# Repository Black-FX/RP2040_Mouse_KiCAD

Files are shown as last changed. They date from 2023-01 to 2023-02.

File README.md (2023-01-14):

# RP2040_Mouse_KiCAD
This is the hardware side of an RP2040 USB to Quadrature mouse adaptor used with retro computers, the software is available at https://github.com/Black-FX/RP2040_Mouse

A PDF of the scematic is available in [Here](PDF/scematic.pdf)

Glamour shots

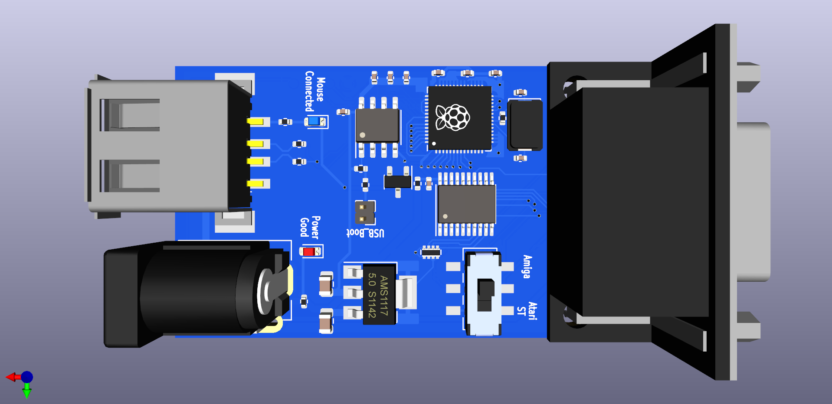
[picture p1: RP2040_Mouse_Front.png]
Front


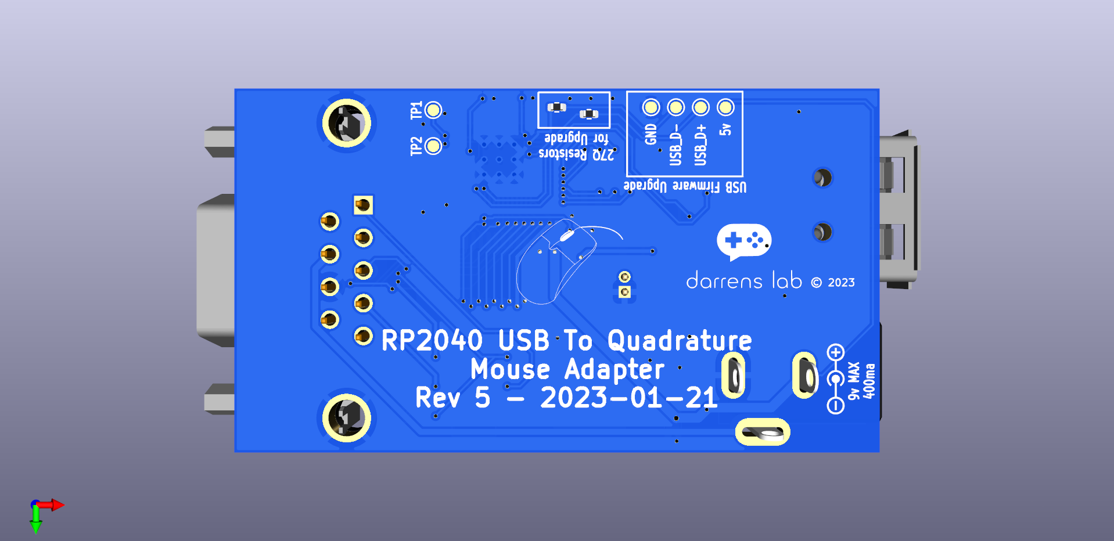
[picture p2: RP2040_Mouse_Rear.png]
Rear


# Ordering

You can order the boards here:

[PCBWay](https://www.pcbway.com/project/shareproject/RP2040_USB_Mouse_to_Quadrature_15de42f1.html)

I sell pre-assembled and programmed ones here:

[Tindie](https://www.tindie.com/products/darrens_lab/rp2040-usb-to-quadrature-mouse-adaptor/)

[EBay](https://www.ebay.com/usr/darrens_lab_nz?_trksid=p2047675.m145687.l151929)

[Trademe NZ & Aus](https://www.trademe.co.nz/a/search?member_listing=7404797&bof=McH9Ulww)

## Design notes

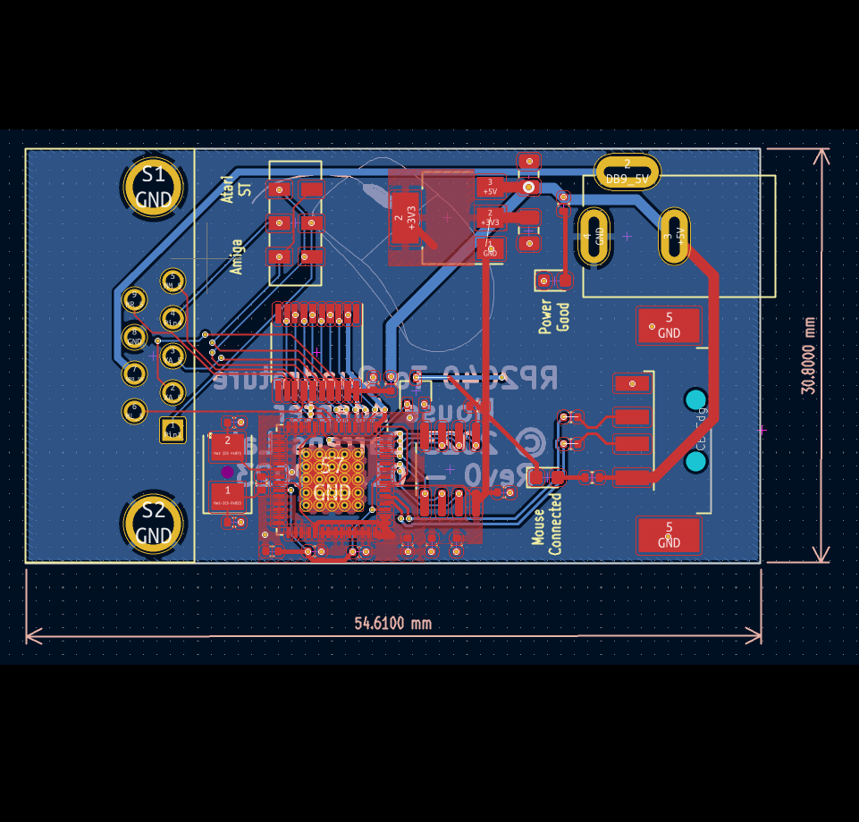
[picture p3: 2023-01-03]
PCB_Layout.png

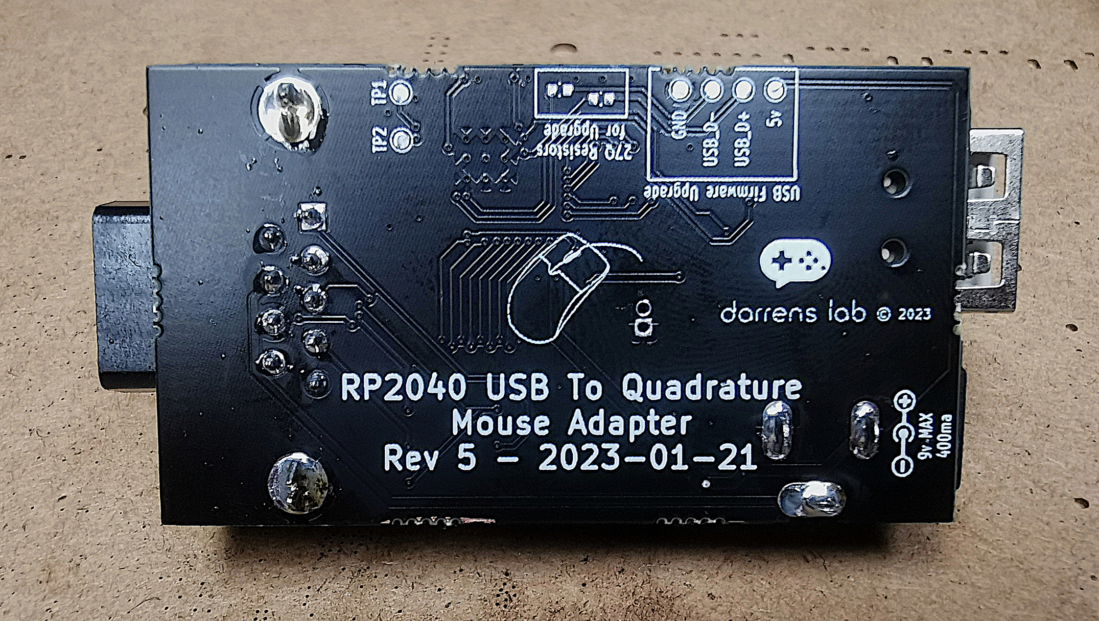
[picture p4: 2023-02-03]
images/IMG_20230203_174929_edit_710155273955179.jpg

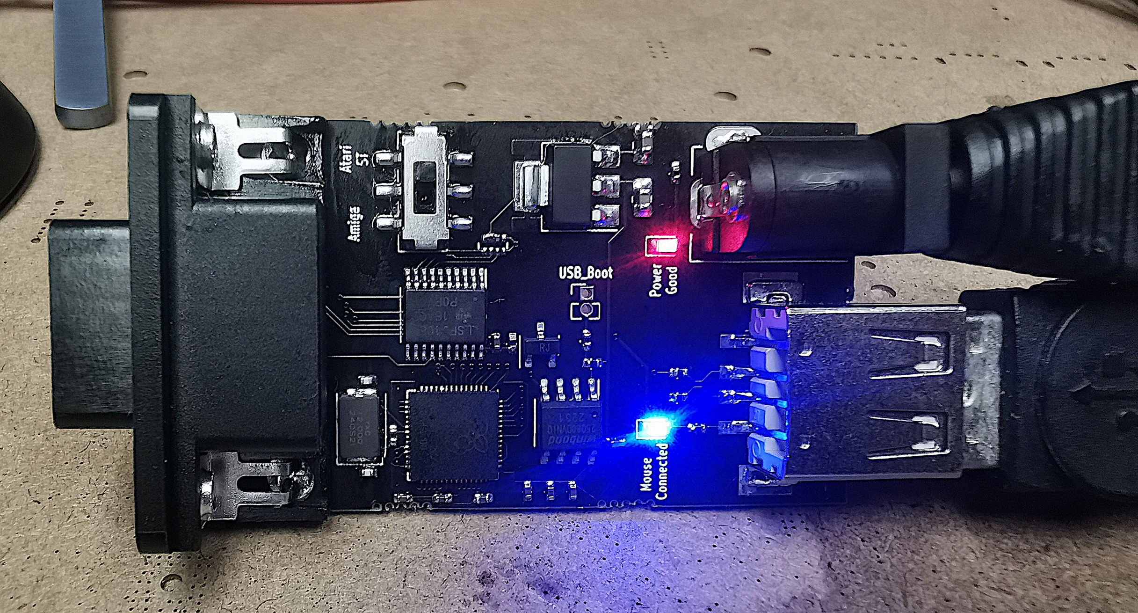
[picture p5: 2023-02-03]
images/IMG_20230203_174809_edit_710135319617161.jpg

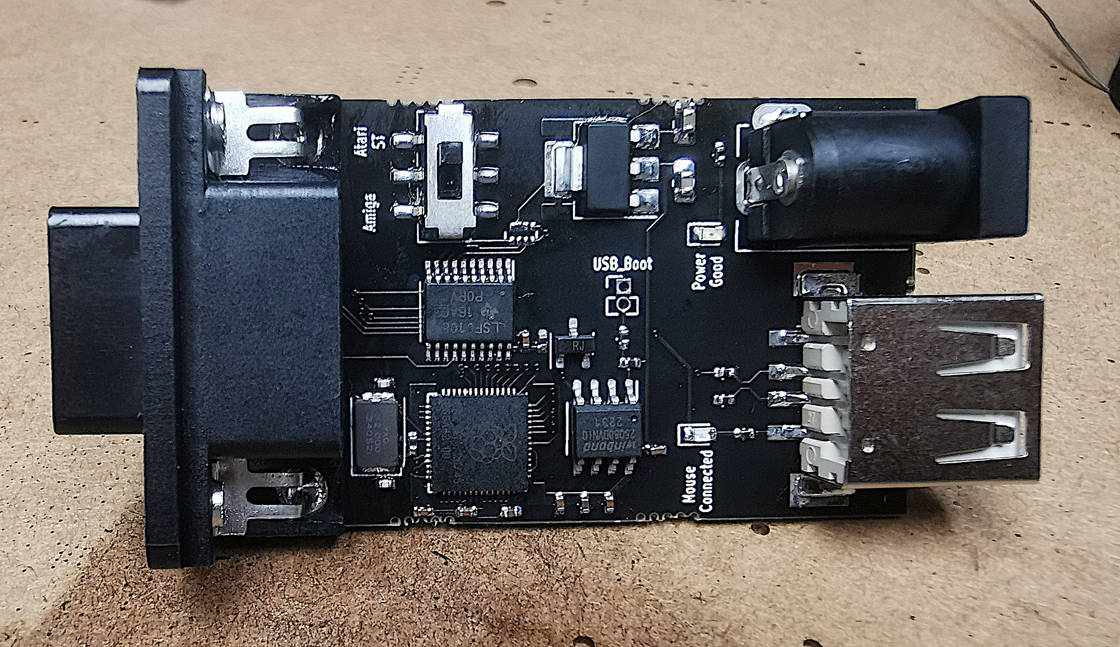
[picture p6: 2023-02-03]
images/IMG_20230203_174900_edit_710110974966644.jpg

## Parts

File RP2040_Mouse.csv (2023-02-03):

Source: | /home/darren/creations/eda/RP2040_Mouse_KiCAD/RP2040_Mouse.kicad_sch
Date: | Mon 30 Jan 2023 19:51:02
Tool: | Eeschema 7.0.0-rc2-unknown-5beb79bbdc~164~ubuntu22.04.1
Generator: | /usr/share/kicad/plugins/bom_csv_grouped_by_value.py
Component Count: | 42
Individual Components:
Item | Qty | Reference(s) | Value | LibPart | Footprint | Datasheet | AVAILABILITY | DESCRIPTION | MF | MP | PACKAGE | PRICE | Part
 |  | C1 | 10u | Device:C_Polarized | Capacitor_SMD:C_0805_2012Metric | ~ |  |  |  |  |  |  | TCJN106M006R0500E
 |  | C2 | 10u | Device:C_Polarized | Capacitor_SMD:C_0805_2012Metric | ~ |  |  |  |  |  |  | TCJN106M006R0500E
 |  | C3 | 100n | Device:C | Capacitor_SMD:C_0402_1005Metric | ~
 |  | C4 | 100n | Device:C | Capacitor_SMD:C_0402_1005Metric | ~
 |  | C5 | 30p | Device:C | Capacitor_SMD:C_0402_1005Metric | ~
 |  | C6 | 30p | Device:C | Capacitor_SMD:C_0402_1005Metric | ~
 |  | C7 | 100n | Device:C | Capacitor_SMD:C_0402_1005Metric | ~
 |  | C8 | 100n | Device:C | Capacitor_SMD:C_0402_1005Metric | ~
 |  | C9 | 1u | Device:C | Capacitor_SMD:C_0402_1005Metric | ~
 |  | C10 | 100n | Device:C | Capacitor_SMD:C_0402_1005Metric | ~
 |  | C11 | 1u | Device:C | Capacitor_SMD:C_0402_1005Metric | ~ |  |  |  |  |  |  | CM05X7S105M04AH-HE
 |  | C12 | 100n | Device:C | Capacitor_SMD:C_0402_1005Metric | ~
 |  | D1 | LED | Device:LED | LED_SMD:LED_0603_1608Metric | ~
 |  | D2 | LED | Device:LED | LED_SMD:LED_0603_1608Metric | ~
 |  | J1 | DB9_Male | Connector:DB9_Male | My Library:ASSMANN_A-DF_09_A_KG-T2S | ~
 |  | J2 | Barrel_Jack_Switch | LSF0108:DC-005 | Library:NINIGI_DC-005 |  | Unavailable | Conn Dc Power Jack 2.1mm | Best Inc. | DC-005 | None | None
 |  | J3 | USB_A | Connector:USB_A | Library:USB_A_China | ~
 |  | JP1 | USB_Boot | Jumper:Jumper_2_Open | Connector_PinHeader_1.27mm:PinHeader_1x02_P1.27mm_Vertical | ~
 |  | Q1 | Q_NPN_BEC | Device:Q_NPN_BEC | Package_TO_SOT_SMD:SOT-23-3 | ~
 |  | R1 | 10K | Device:R_Small_US | Resistor_SMD:R_0402_1005Metric | ~
 |  | R2 | 180K | Device:R_Small_US | Resistor_SMD:R_0402_1005Metric | ~
 |  | R3 | 1K5 | Device:R_Small_US | Resistor_SMD:R_0402_1005Metric | ~
 |  | R4 | 22R | Device:R_Small_US | Resistor_SMD:R_0402_1005Metric | ~
 |  | R5 | 22R | Device:R_Small_US | Resistor_SMD:R_0402_1005Metric | ~
 |  | R6 | 1K5 | Device:R_Small_US | Resistor_SMD:R_0402_1005Metric | ~
 |  | R7 | 1K5 | Device:R_Small_US | Resistor_SMD:R_0402_1005Metric | ~
 |  | R8 | 1K5 | Device:R_Small_US | Resistor_SMD:R_0402_1005Metric | ~
 |  | R9 | 22R | Device:R_Small_US | Resistor_SMD:R_0402_1005Metric | ~
 |  | R10 | 22R | Device:R_Small_US | Resistor_SMD:R_0402_1005Metric | ~
 |  | RN1 | R_Pack04 | Device:R_Pack04 | Resistor_SMD:R_Array_Concave_4x0402 | ~
 |  | SW1 | SW_DPDT_x2 | Switch:SW_DPDT_x2 | Button_Switch_SMD:SW_DPDT_CK_JS202011JCQN | ~
 |  | TP1 | SWD | Connector:TestPoint | TestPoint:TestPoint_Pad_D1.0mm | ~
 |  | TP2 | SWCLK | Connector:TestPoint | TestPoint:TestPoint_Pad_D1.0mm | ~
 |  | TP3 | USB_D+ | Connector:TestPoint | TestPoint:TestPoint_Pad_D1.0mm | ~
 |  | TP4 | USB_D- | Connector:TestPoint | TestPoint:TestPoint_Pad_D1.0mm | ~
 |  | TP5 | 5v | Connector:TestPoint | TestPoint:TestPoint_Pad_D1.0mm | ~
 |  | TP6 | GND | Connector:TestPoint | TestPoint:TestPoint_Pad_D1.0mm | ~
 |  | U1 | LSF0108PWR | LSF0108:LSF0108PWR | Package_SO:TSSOP-20_4.4x6.5mm_P0.65mm
 |  | U2 | RP2040 | RP2040:RP2040 | Library:RP2040-QFN-56
 |  | U3 | AT25SF081B-SSHD-T | Memory_Flash:W25Q32JVZP | Package_SO:SOIC-8-1EP_3.9x4.9mm_P1.27mm_EP2.29x3mm | http://www.winbond.com/resource-files/w25q32jv%20revg%2003272018%20plus.pdf
 |  | U4 | AMS1117-3.3 | Regulator_Linear:AMS1117-3.3 | Package_TO_SOT_SMD:SOT-223-3_TabPin2 | http://www.advanced-monolithic.com/pdf/ds1117.pdf
 |  | Y1 | 12MHZ | Device:Crystal | Crystal:Crystal_SMD_5032-2Pin_5.0x3.2mm | ~
Collated Components:
Item | Qty | Reference(s) | Value | LibPart | Footprint | Datasheet | AVAILABILITY | DESCRIPTION | MF | MP | PACKAGE | PRICE | Part
1 | 2 | C1, C2 | 10u | Device:C_Polarized | Capacitor_SMD:C_0805_2012Metric | ~ |  |  |  |  |  |  | TCJN106M006R0500E
2 | 6 | C3, C4, C7, C8, C10, C12 | 100n | Device:C | Capacitor_SMD:C_0402_1005Metric | ~
3 | 2 | C5, C6 | 30p | Device:C | Capacitor_SMD:C_0402_1005Metric | ~
4 | 2 | C9, C11 | 1u | Device:C | Capacitor_SMD:C_0402_1005Metric | ~ |  |  |  |  |  |  | CM05X7S105M04AH-HE
5 | 2 | D1, D2 | LED | Device:LED | LED_SMD:LED_0603_1608Metric | ~
6 | 1 | J1 | DB9_Male | Connector:DB9_Male | My Library:ASSMANN_A-DF_09_A_KG-T2S | ~
7 | 1 | J2 | Barrel_Jack_Switch | LSF0108:DC-005 | Library:NINIGI_DC-005 |  | Unavailable | Conn Dc Power Jack 2.1mm | Best Inc. | DC-005 | None | None
8 | 1 | J3 | USB_A | Connector:USB_A | Library:USB_A_China | ~
9 | 1 | JP1 | USB_Boot | Jumper:Jumper_2_Open | Connector_PinHeader_1.27mm:PinHeader_1x02_P1.27mm_Vertical | ~
10 | 1 | Q1 | Q_NPN_BEC | Device:Q_NPN_BEC | Package_TO_SOT_SMD:SOT-23-3 | ~
11 | 1 | R1 | 10K | Device:R_Small_US | Resistor_SMD:R_0402_1005Metric | ~
12 | 1 | R2 | 180K | Device:R_Small_US | Resistor_SMD:R_0402_1005Metric | ~
13 | 4 | R3, R6, R7, R8 | 1K5 | Device:R_Small_US | Resistor_SMD:R_0402_1005Metric | ~
14 | 4 | R4, R5, R9, R10 | 22R | Device:R_Small_US | Resistor_SMD:R_0402_1005Metric | ~
15 | 1 | RN1 | R_Pack04 | Device:R_Pack04 | Resistor_SMD:R_Array_Concave_4x0402 | ~
16 | 1 | SW1 | SW_DPDT_x2 | Switch:SW_DPDT_x2 | Button_Switch_SMD:SW_DPDT_CK_JS202011JCQN | ~
17 | 1 | TP1 | SWD | Connector:TestPoint | TestPoint:TestPoint_Pad_D1.0mm | ~
18 | 1 | TP2 | SWCLK | Connector:TestPoint | TestPoint:TestPoint_Pad_D1.0mm | ~
19 | 1 | TP3 | USB_D+ | Connector:TestPoint | TestPoint:TestPoint_Pad_D1.0mm | ~
20 | 1 | TP4 | USB_D- | Connector:TestPoint | TestPoint:TestPoint_Pad_D1.0mm | ~
21 | 1 | TP5 | 5v | Connector:TestPoint | TestPoint:TestPoint_Pad_D1.0mm | ~
22 | 1 | TP6 | GND | Connector:TestPoint | TestPoint:TestPoint_Pad_D1.0mm | ~
23 | 1 | U1 | LSF0108PWR | LSF0108:LSF0108PWR | Package_SO:TSSOP-20_4.4x6.5mm_P0.65mm
24 | 1 | U2 | RP2040 | RP2040:RP2040 | Library:RP2040-QFN-56
25 | 1 | U3 | AT25SF081B-SSHD-T | Memory_Flash:W25Q32JVZP | Package_SO:SOIC-8-1EP_3.9x4.9mm_P1.27mm_EP2.29x3mm | http://www.winbond.com/resource-files/w25q32jv%20revg%2003272018%20plus.pdf
26 | 1 | U4 | AMS1117-3.3 | Regulator_Linear:AMS1117-3.3 | Package_TO_SOT_SMD:SOT-223-3_TabPin2 | http://www.advanced-monolithic.com/pdf/ds1117.pdf
27 | 1 | Y1 | 12MHZ | Device:Crystal | Crystal:Crystal_SMD_5032-2Pin_5.0x3.2mm | ~

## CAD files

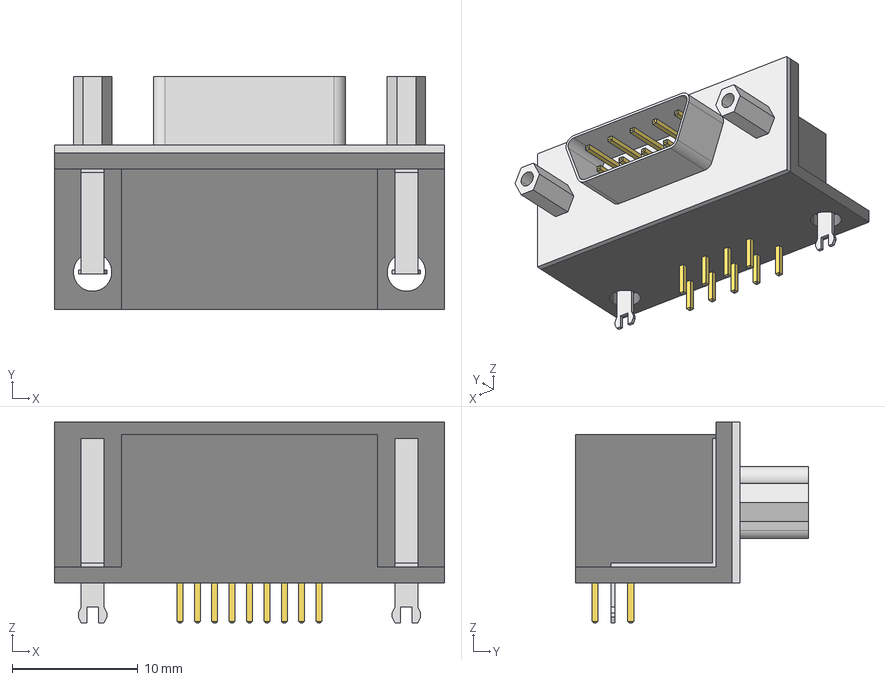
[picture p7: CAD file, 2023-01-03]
3d_models/CONN_A-DF09AKG-T2S_ASM.step
31.1 x 18.6 x 16.0 mm

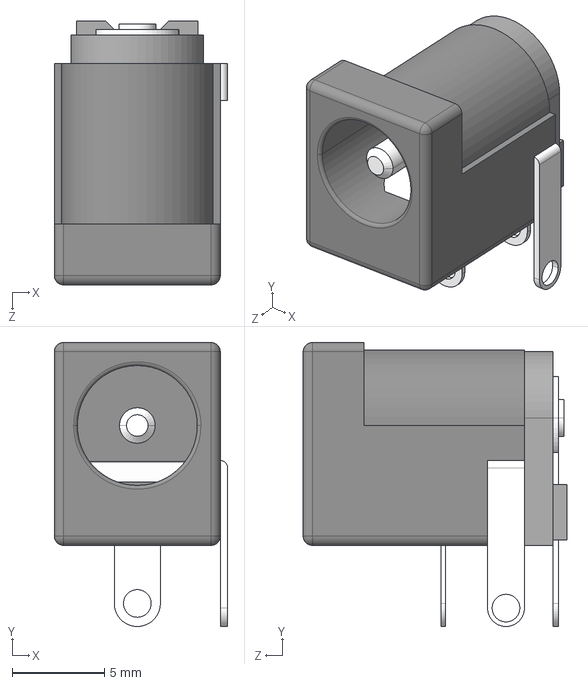
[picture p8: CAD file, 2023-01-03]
3d_models/DC-005.STEP
9.40 x 15.4 x 14.3 mm

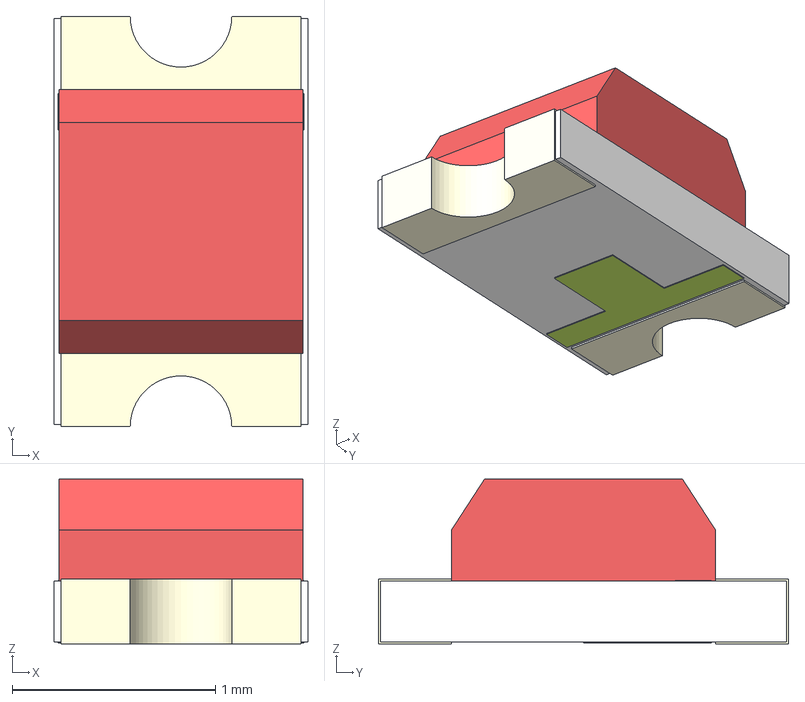
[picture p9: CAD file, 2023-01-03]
3d_models/LED-0805-Red.step
1.25 x 2.02 x 0.81 mm
Pads
Glass
Marks
Chip

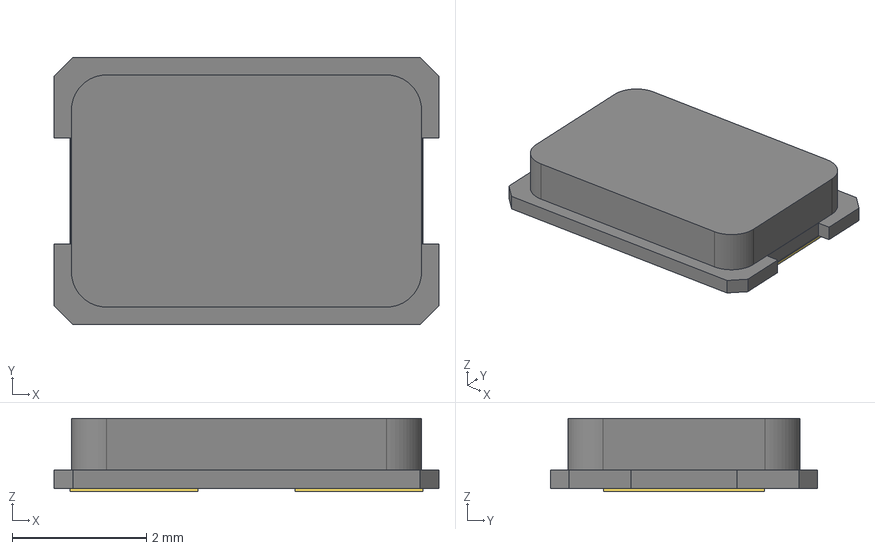
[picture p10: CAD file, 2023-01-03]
3d_models/xtal2_CX5032GB_AVX.step
5.73 x 3.98 x 1.09 mm

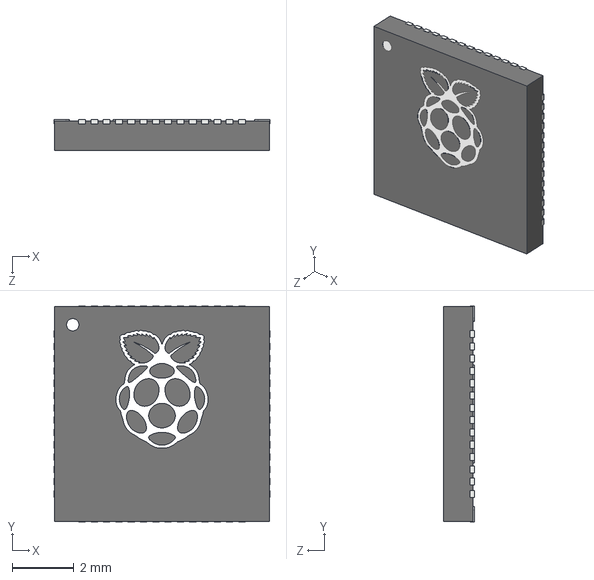
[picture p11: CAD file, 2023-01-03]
3d_models/RP2040_QFN_PACKAGE.STEP
7.02 x 7.02 x 1.00 mm

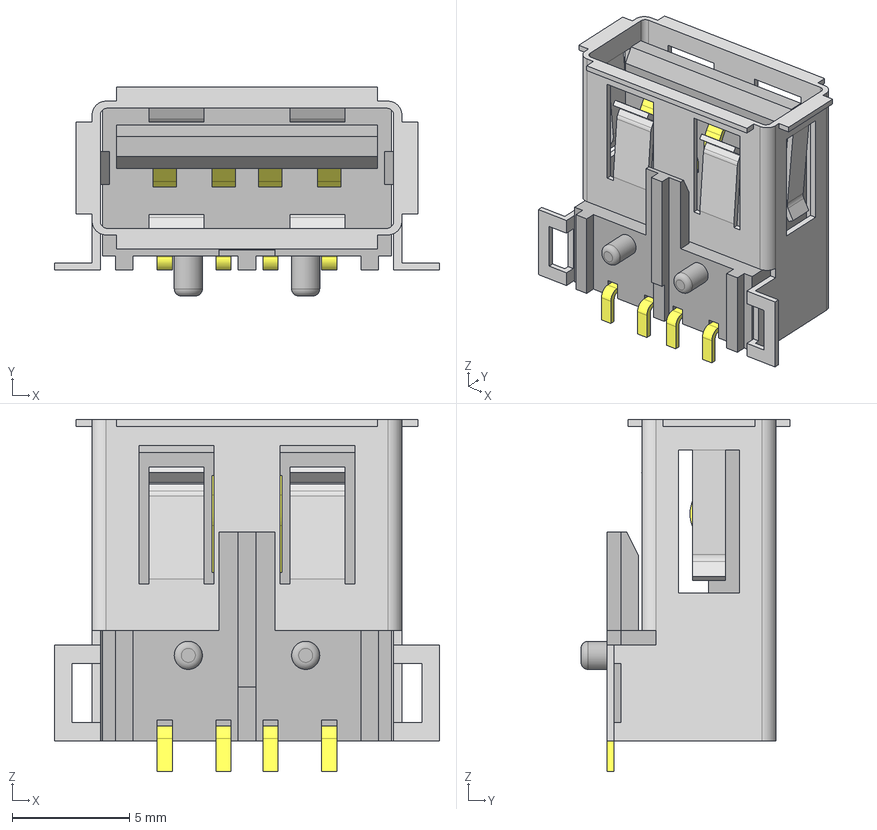
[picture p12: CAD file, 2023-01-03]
3d_models/USB-A-S-F-B-SM2-TR.stp
16.4 x 8.90 x 15.0 mm
USB-A-S-SM2_P
USB-A-S-B-SM2_B
USB-A-S-SM2_S

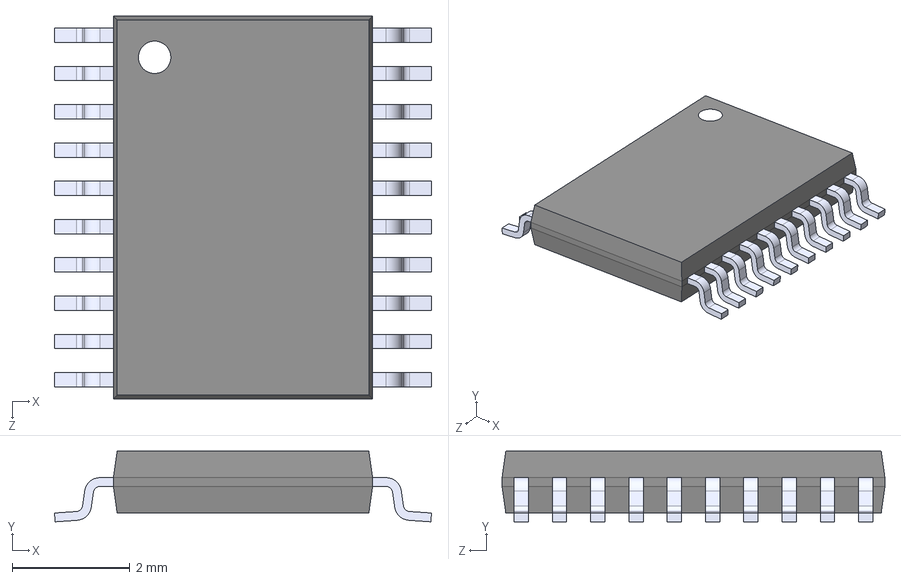
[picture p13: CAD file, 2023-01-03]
3d_models/LSF0108PWR.step
6.40 x 1.20 x 6.50 mm

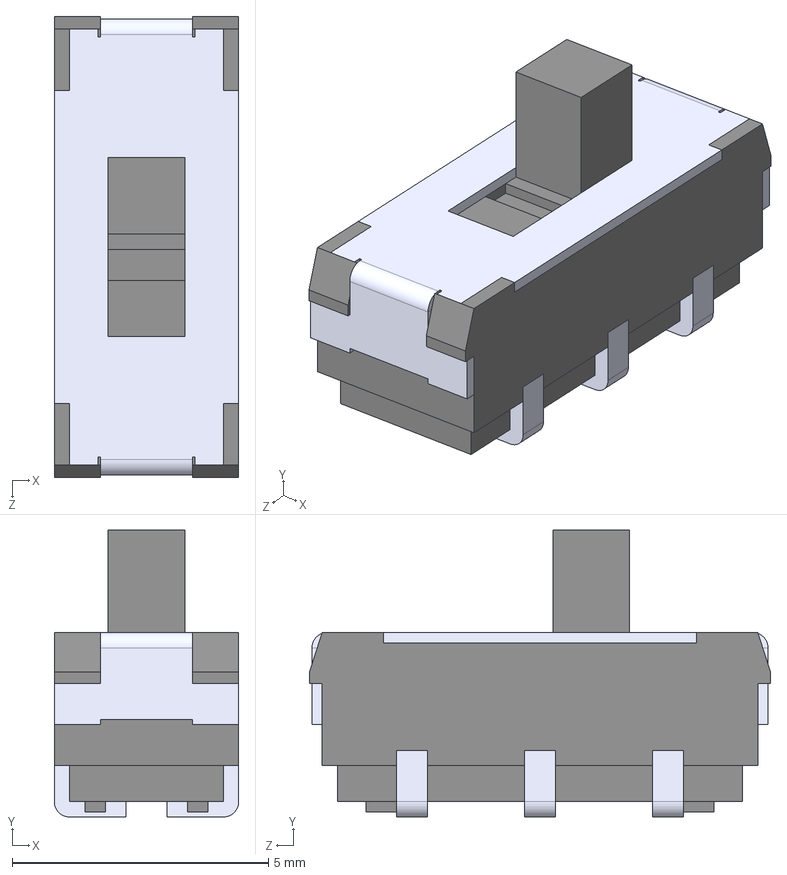
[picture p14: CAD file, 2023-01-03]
3d_models/JS202011JCQN--3DModel-STEP-1.STEP
3.60 x 5.60 x 9.00 mm

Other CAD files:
3d_models/LED-0805-Blue.step

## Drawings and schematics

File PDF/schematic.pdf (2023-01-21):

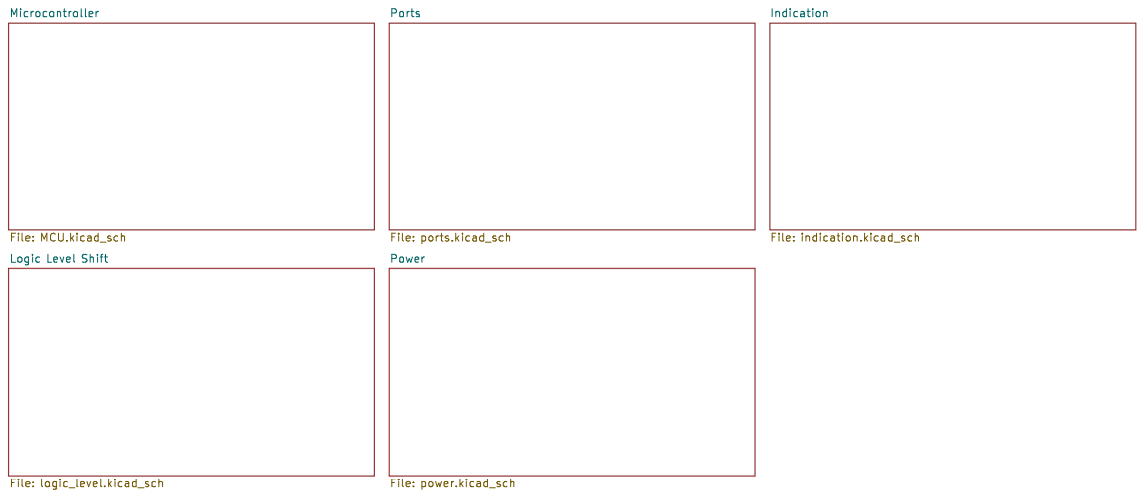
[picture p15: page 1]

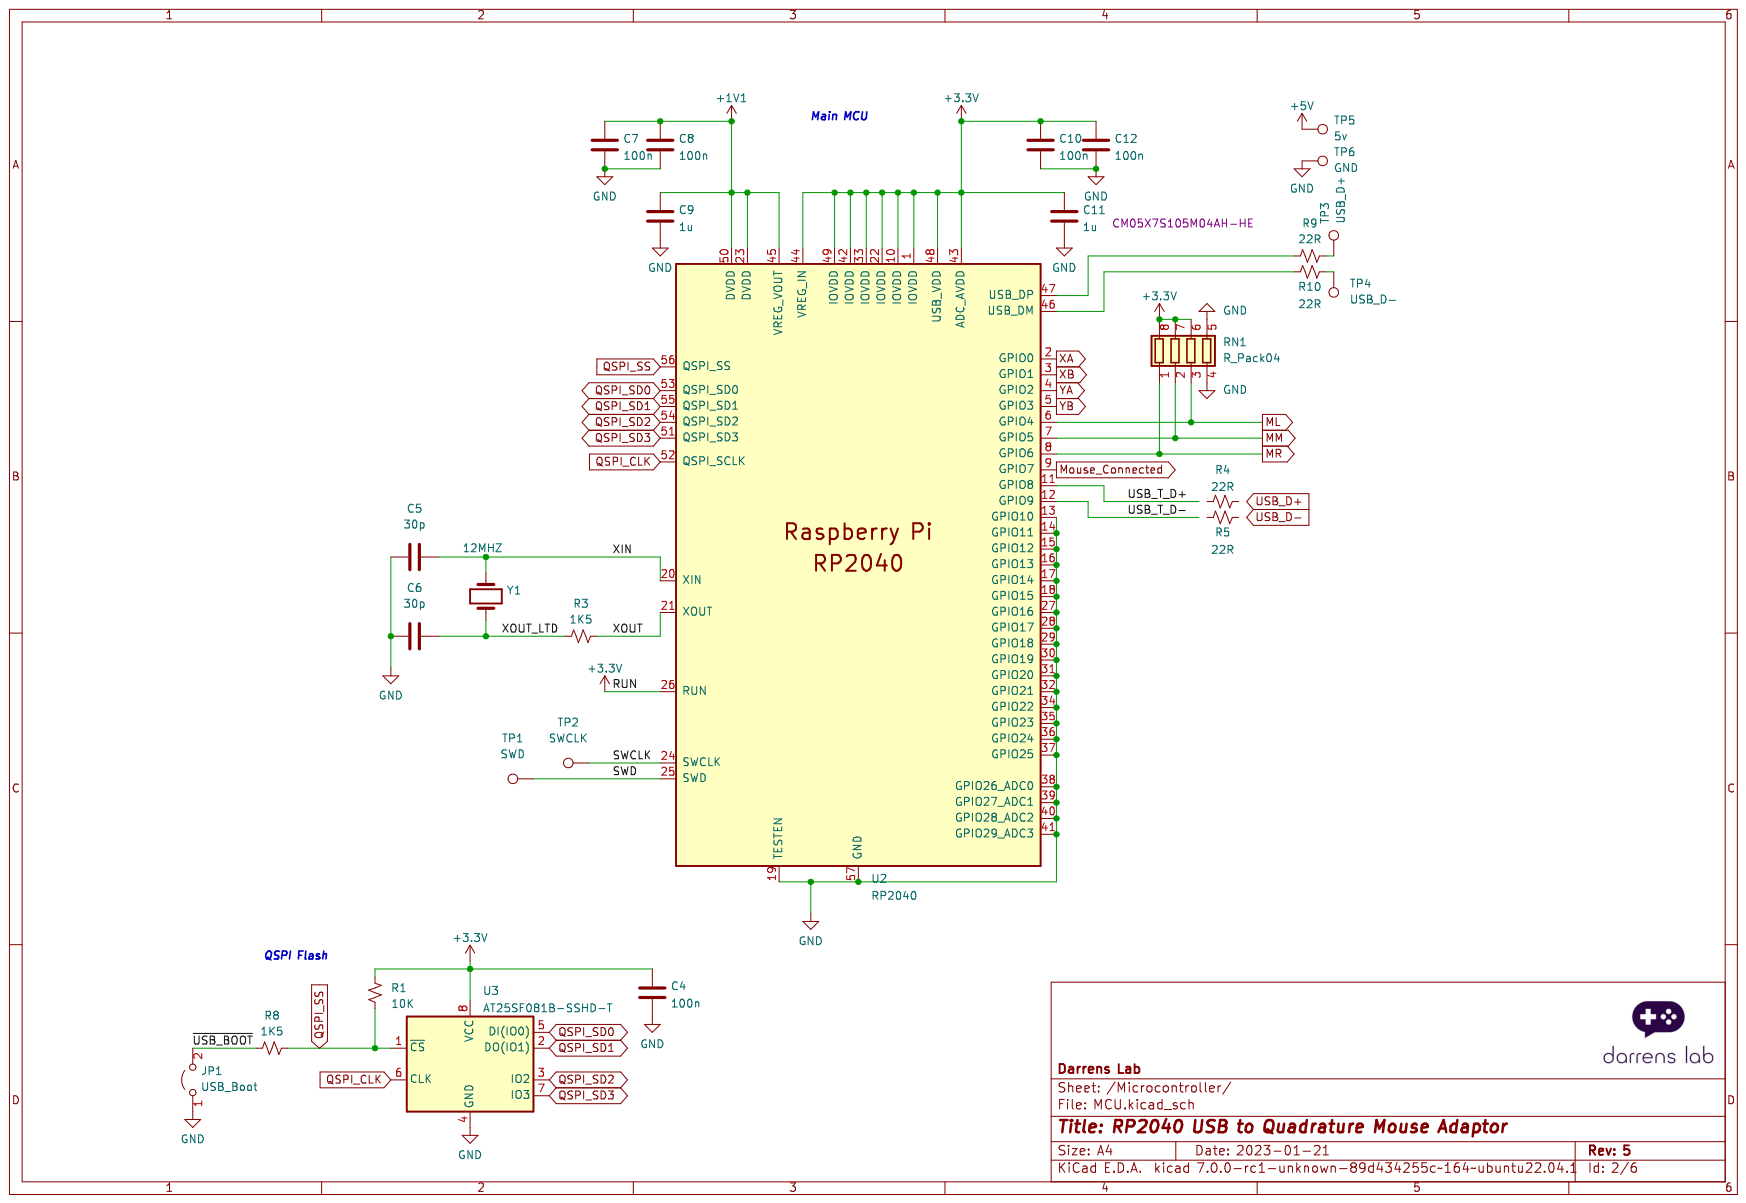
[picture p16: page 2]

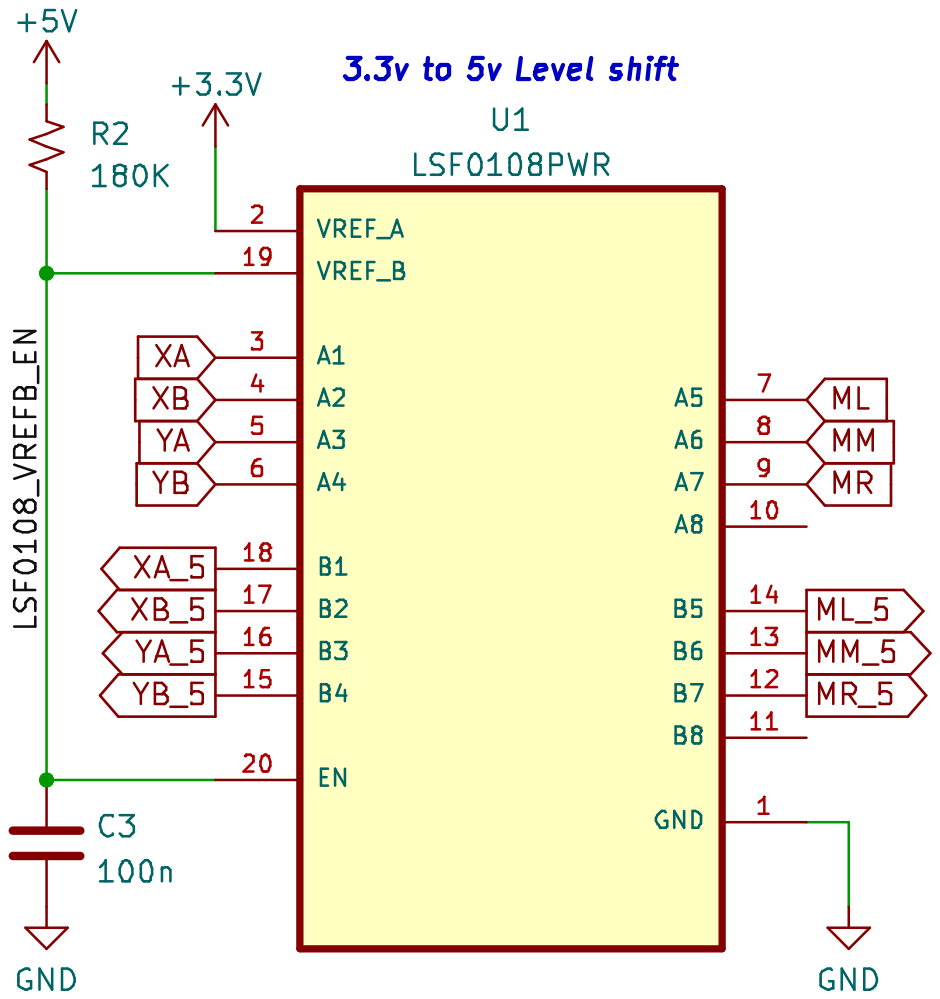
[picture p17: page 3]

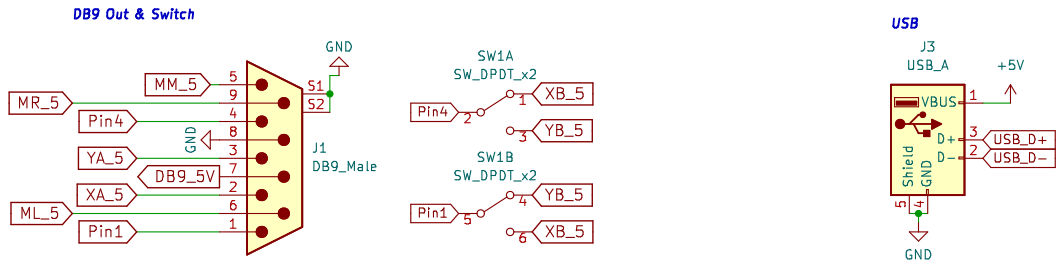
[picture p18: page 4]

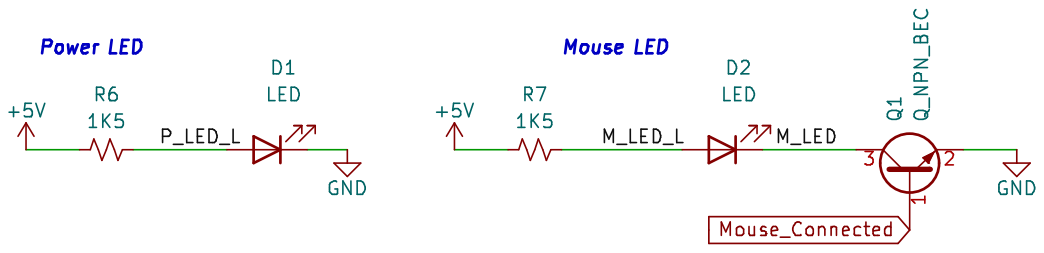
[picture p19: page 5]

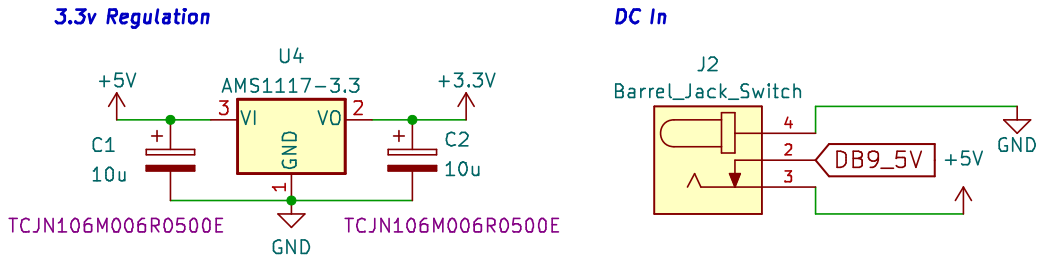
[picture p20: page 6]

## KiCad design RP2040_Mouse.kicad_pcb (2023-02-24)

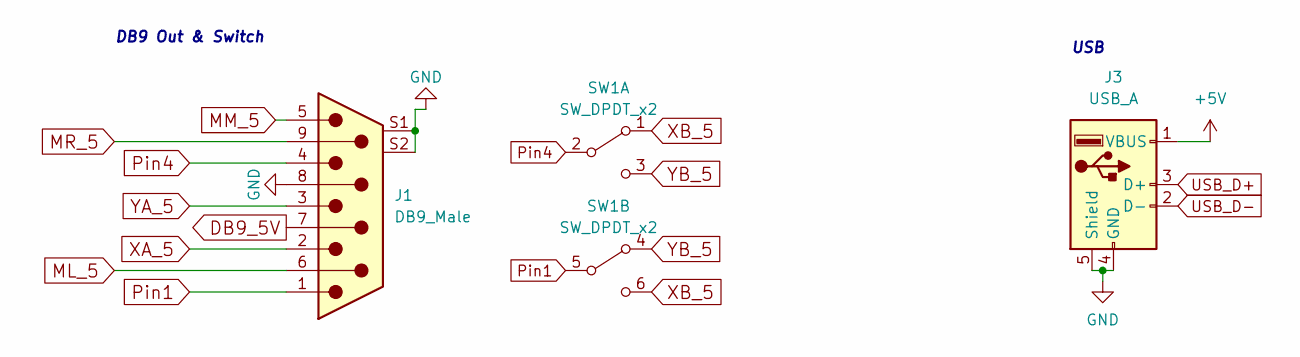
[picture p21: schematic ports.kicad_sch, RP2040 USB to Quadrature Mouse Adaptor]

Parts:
J1: DB9_Male; ASSMANN_A-DF_09_A_KG-T2S
J3: USB_A; USB_A_China
SW1: SW_DPDT_x2; SW_DPDT_CK_JS202011JCQN

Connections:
+5V: J3.1 (VBUS); also elsewhere on the board
DB9_5V: J1.7; also elsewhere on the board
GND: J1.8, J1.S1, J1.S2, J3.4 (GND), J3.5 (Shield); also elsewhere on the board
ML_5: J1.6; also elsewhere on the board
MM_5: J1.5; also elsewhere on the board
MR_5: J1.9; also elsewhere on the board
Pin1: J1.1, SW1.5 (B)
Pin4: J1.4, SW1.2 (B)
USB_D+: J3.3 (D+); also elsewhere on the board
USB_D-: J3.2 (D-); also elsewhere on the board
XA_5: J1.2; also elsewhere on the board
XB_5: SW1.1 (A), SW1.6 (C); also elsewhere on the board
YA_5: J1.3; also elsewhere on the board
YB_5: SW1.3 (C), SW1.4 (A); also elsewhere on the board

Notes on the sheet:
USB
DB9 Out & Switch

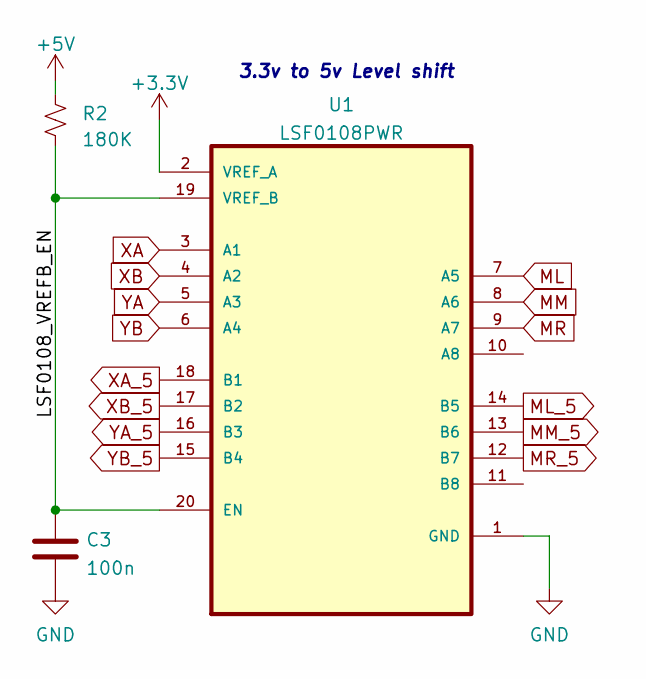
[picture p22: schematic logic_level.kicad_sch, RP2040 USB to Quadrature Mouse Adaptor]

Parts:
C3: 100n; C_0402_1005Metric
R2: 180K; R_0402_1005Metric
U1: LSF0108PWR; TSSOP-20_4.4x6.5mm_P0.65mm

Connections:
+3V3: U1.2 (VREF_A); also elsewhere on the board
+5V: R2.1; also elsewhere on the board
/Logic Level Shift/LSF0108_VREFB_EN: C3.1, R2.2, U1.19 (VREF_B), U1.20 (EN)
GND: C3.2, U1.1 (GND); also elsewhere on the board
ML: U1.7 (A5); also elsewhere on the board
ML_5: U1.14 (B5); also elsewhere on the board
MM: U1.8 (A6); also elsewhere on the board
MM_5: U1.13 (B6); also elsewhere on the board
MR: U1.9 (A7); also elsewhere on the board
MR_5: U1.12 (B7); also elsewhere on the board
XA: U1.3 (A1); also elsewhere on the board
XA_5: U1.18 (B1); also elsewhere on the board
XB: U1.4 (A2); also elsewhere on the board
XB_5: U1.17 (B2); also elsewhere on the board
YA: U1.5 (A3); also elsewhere on the board
YA_5: U1.16 (B3); also elsewhere on the board
YB: U1.6 (A4); also elsewhere on the board
YB_5: U1.15 (B4); also elsewhere on the board

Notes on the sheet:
3.3v to 5v Level shift

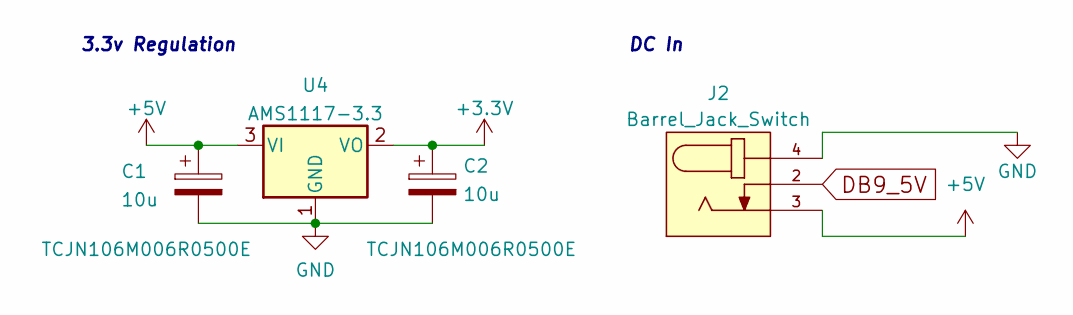
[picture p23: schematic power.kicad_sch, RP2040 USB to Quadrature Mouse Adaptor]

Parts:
C1, C2: 10u; C_0805_2012Metric; Part TCJN106M006R0500E
J2: Barrel_Jack_Switch; NINIGI_DC-005
U4: AMS1117-3.3; SOT-223-3_TabPin2

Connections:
+3V3: C2.1, U4.2 (VO); also elsewhere on the board
+5V: C1.1, J2.3, U4.3 (VI); also elsewhere on the board
DB9_5V: J2.2; also elsewhere on the board
GND: C1.2, C2.2, J2.4, U4.1 (GND); also elsewhere on the board

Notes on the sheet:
3.3v Regulation
DC In

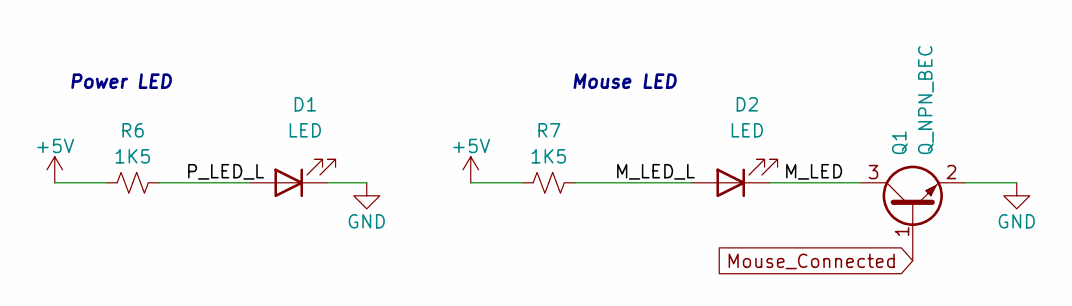
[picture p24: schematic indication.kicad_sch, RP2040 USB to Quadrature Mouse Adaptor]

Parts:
D1, D2: LED; LED_0603_1608Metric
Q1: Q_NPN_BEC; SOT-23-3
R6, R7: 1K5; R_0402_1005Metric

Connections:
+5V: R6.1, R7.1; also elsewhere on the board
/Indication/M_LED: D2.1 (K), Q1.3 (C)
/Indication/M_LED_L: D2.2 (A), R7.2
/Indication/P_LED_L: D1.2 (A), R6.2
GND: D1.1 (K), Q1.2 (E); also elsewhere on the board
Mouse_Connected: Q1.1 (B); also elsewhere on the board

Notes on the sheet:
Mouse LED
Power LED

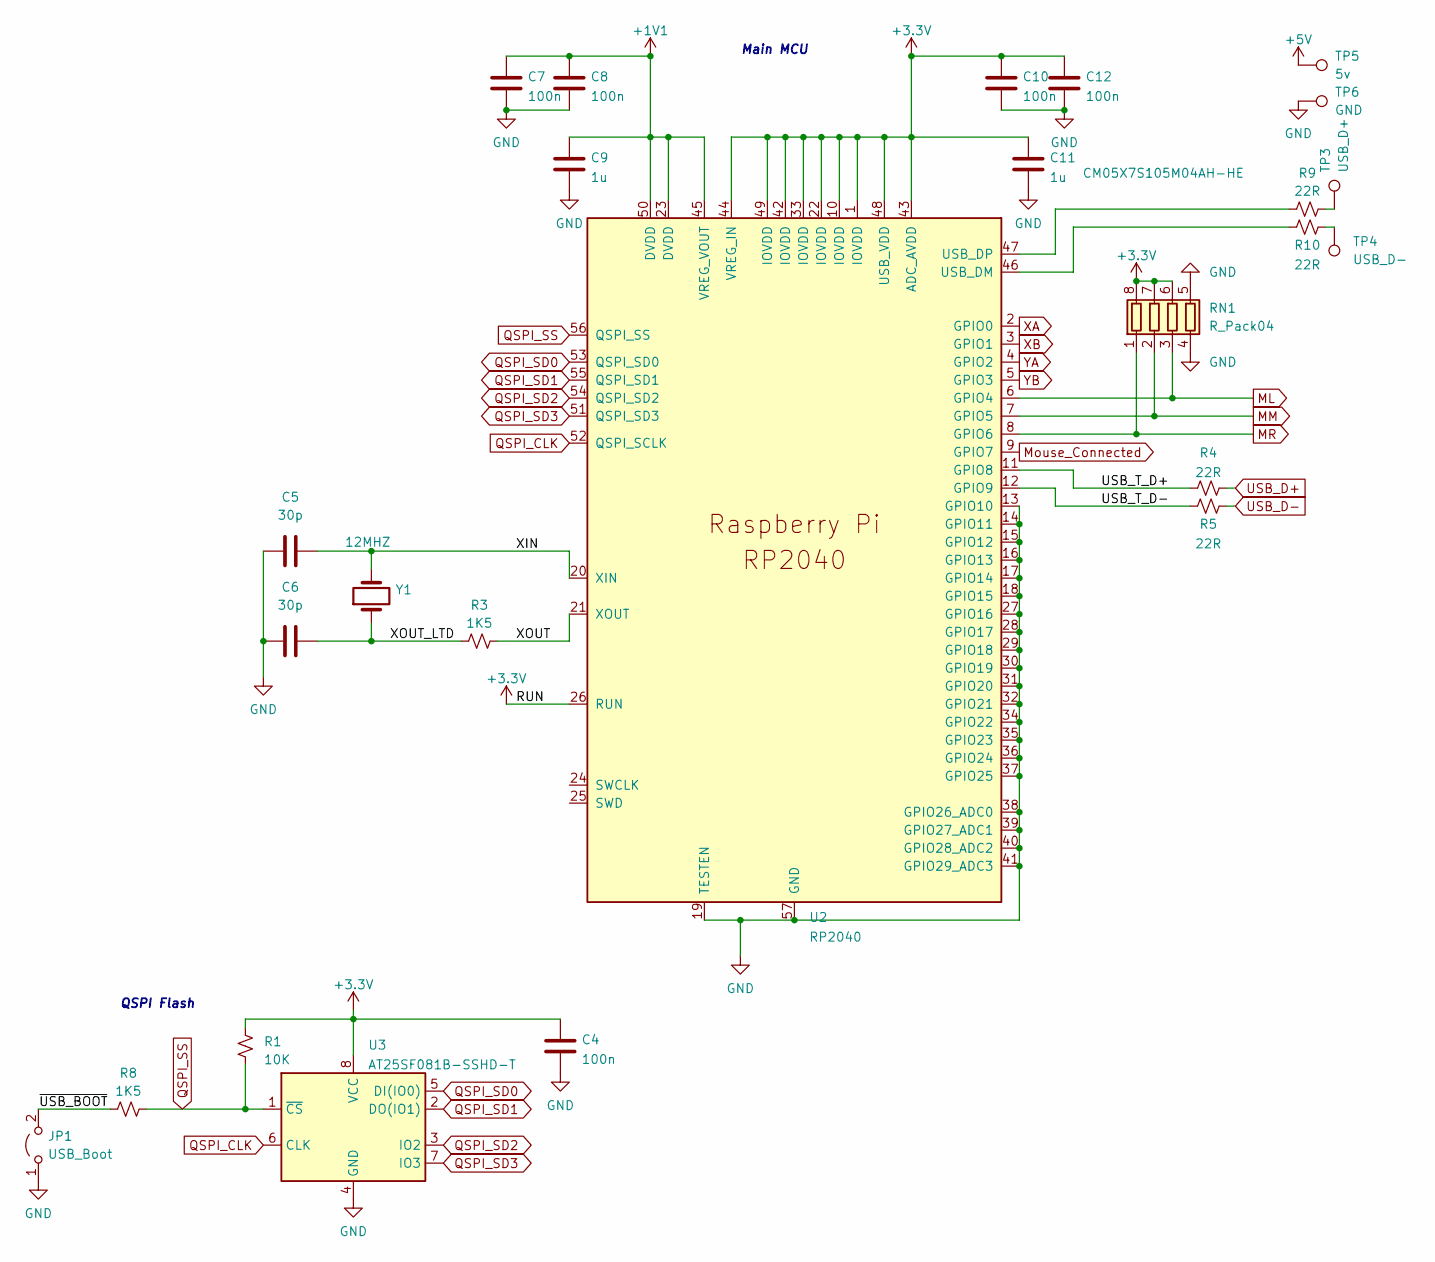
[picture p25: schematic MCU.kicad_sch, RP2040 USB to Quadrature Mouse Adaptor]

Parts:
C4, C7, C8, C10, C12: 100n; C_0402_1005Metric
C5, C6: 30p; C_0402_1005Metric
C9: 1u; C_0402_1005Metric
C11: 1u; C_0402_1005Metric; Part CM05X7S105M04AH-HE
JP1: USB_Boot; PinHeader_1x02_P1.27mm_Vertical
R1: 10K; R_0402_1005Metric
R3, R8: 1K5; R_0402_1005Metric
R4, R5, R9, R10: 22R; R_0402_1005Metric
RN1: R_Pack04; R_Array_Concave_4x0402
TP3: USB_D+; TestPoint_Pad_D1.0mm
TP4: USB_D-; TestPoint_Pad_D1.0mm
TP5: 5v; TestPoint_Pad_D1.0mm
TP6: GND; TestPoint_Pad_D1.0mm
U2: RP2040; RP2040-QFN-56
U3: AT25SF081B-SSHD-T; SOIC-8-1EP_3.9x4.9mm_P1.27mm_EP2.29x3mm
Y1: 12MHZ; Crystal_SMD_5032-2Pin_5.0x3.2mm

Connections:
+1V1: C7.1, C8.1, C9.1, U2.23 (DVDD), U2.45 (VREG_VOUT), U2.50 (DVDD)
+3V3: C4.1, C10.1, C11.1, C12.1, R1.1, RN1.6 (R3.2), RN1.7 (R2.2), RN1.8 (R1.2), U2.1 (IOVDD), U2.10 (IOVDD), U2.22 (IOVDD), U2.26 (RUN), U2.33 (IOVDD), U2.42 (IOVDD), U2.43 (ADC_AVDD), U2.44 (VREG_IN), U2.48 (USB_VDD), U2.49 (IOVDD), U3.8 (VCC); also elsewhere on the board
+5V: TP5.1; also elsewhere on the board
/Microcontroller/USB_T_D+: R4.1, U2.11 (GPIO8)
/Microcontroller/USB_T_D-: R5.2, U2.12 (GPIO9)
/Microcontroller/XIN: C5.2, U2.20 (XIN), Y1.2
/Microcontroller/XOUT: R3.2, U2.21 (XOUT)
/Microcontroller/XOUT_LTD: C6.2, R3.1, Y1.1
/Microcontroller/~USB_BOOT: JP1.2 (B), R8.1
GND: C4.2, C5.1, C6.1, C7.2, C8.2, C9.2, C10.2, C11.2, C12.2, JP1.1 (A), RN1.4 (R4.1), RN1.5 (R4.2), TP6.1, U2.13 (GPIO10), U2.14 (GPIO11), U2.15 (GPIO12), U2.16 (GPIO13), U2.17 (GPIO14), U2.18 (GPIO15), U2.19 (TESTEN), U2.27 (GPIO16), U2.28 (GPIO17), U2.29 (GPIO18), U2.30 (GPIO19), U2.31 (GPIO20), U2.32 (GPIO21), U2.34 (GPIO22), U2.35 (GPIO23), U2.36 (GPIO24), U2.37 (GPIO25), U2.38 (GPIO26_ADC0), U2.39 (GPIO27_ADC1), U2.40 (GPIO28_ADC2), U2.41 (GPIO29_ADC3), U2.57 (GND), U3.4 (GND); also elsewhere on the board
ML: RN1.3 (R3.1), U2.6 (GPIO4); also elsewhere on the board
MM: RN1.2 (R2.1), U2.7 (GPIO5); also elsewhere on the board
MR: RN1.1 (R1.1), U2.8 (GPIO6); also elsewhere on the board
Mouse_Connected: U2.9 (GPIO7); also elsewhere on the board
unnamed: R9.2, TP3.1
unnamed: R10.1, TP4.1
unnamed: R10.2, U2.46 (USB_DM)
unnamed: R9.1, U2.47 (USB_DP)
QSPI_CLK: U2.52 (QSPI_SCLK), U3.6 (CLK)
QSPI_SD0: U2.53 (QSPI_SD0), U3.5 (DI(IO0))
QSPI_SD1: U2.55 (QSPI_SD1), U3.2 (DO(IO1))
QSPI_SD2: U2.54 (QSPI_SD2), U3.3 (IO2)
QSPI_SD3: U2.51 (QSPI_SD3), U3.7 (IO3)
QSPI_SS: R1.2, R8.2, U2.56 (QSPI_SS), U3.1 (~CS)
USB_D+: R4.2; also elsewhere on the board
USB_D-: R5.1; also elsewhere on the board
XA: U2.2 (GPIO0); also elsewhere on the board
XB: U2.3 (GPIO1); also elsewhere on the board
YA: U2.4 (GPIO2); also elsewhere on the board
YB: U2.5 (GPIO3); also elsewhere on the board

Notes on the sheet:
Main MCU
QSPI Flash

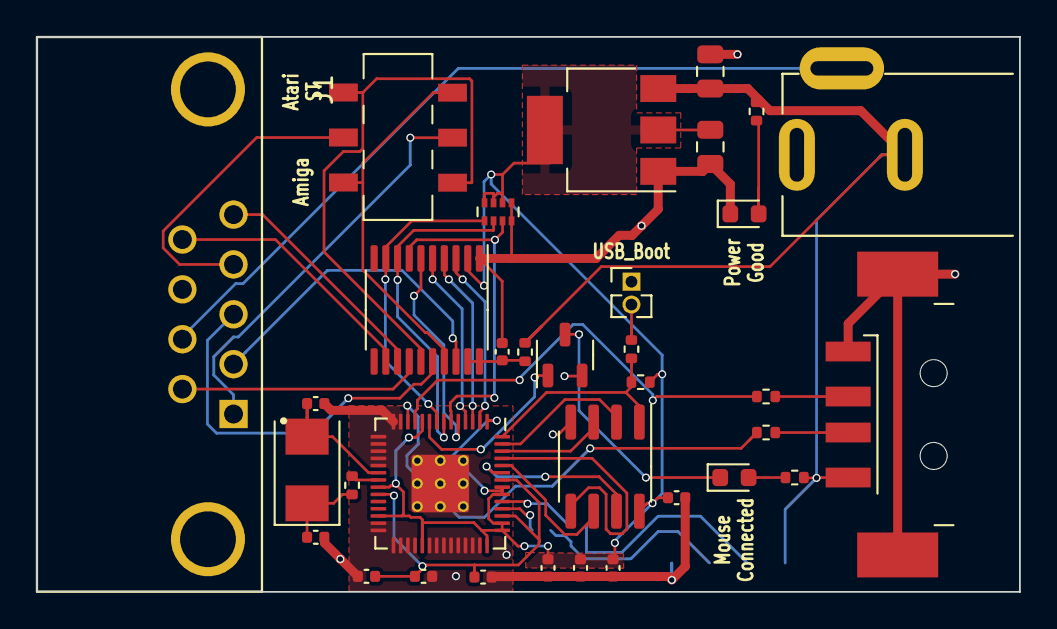
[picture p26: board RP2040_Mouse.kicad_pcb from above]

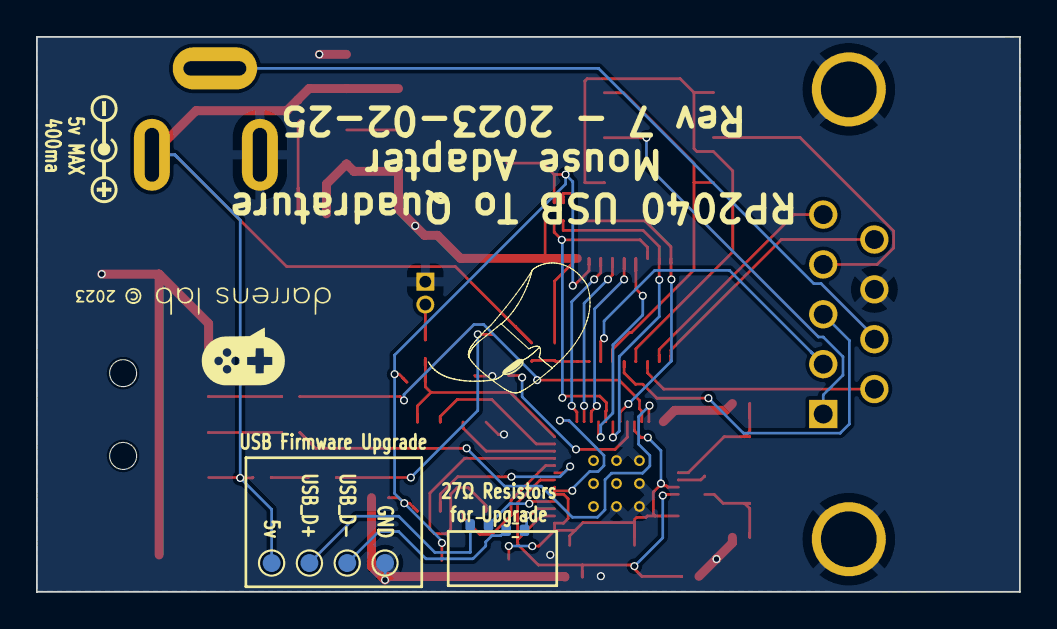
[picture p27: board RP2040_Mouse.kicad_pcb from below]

Board: 2 copper layers, 54.6 x 30.8 mm, 40 parts (6 on the bottom side), 44 nets.

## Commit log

2023-01-03 Inital commit
    [CONN_A-DF09AKG-T2S_ASM.step, DC-005.STEP, JS202011JCQN--3DModel-STEP-1.STEP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]
2023-01-03 Tidy up file locations
    [CONN_A-DF09AKG-T2S_ASM.step, DC-005.STEP, JS202011JCQN--3DModel-STEP-1.STEP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]
2023-01-03 Clean up unused files
    [RP2040_Mouse (copy).kicad_pcb]
2023-01-08 Added pullup resistors on mouse buttons, added breakout points for user software updates
    [RP2040_Mouse.kicad_pcb, RP2040_Mouse.kicad_sch, RP2040_Mouse_Pricing.ods]
2023-01-12 New board not using default USB pins
    [RP2040_Mouse.kicad_sch]
2023-01-14 Rev 4, swap the USB pins around to match the requirements of Tinyusb. Add PDF scematic Update 3d renders
    [RP2040_Mouse.kicad_pcb, RP2040_Mouse.kicad_sch]
2023-01-14 Generate BOM Crop images
    [RP2040_Mouse.csv]
2023-01-16 Updated images and board
2023-01-16 Merging local branches
    [RP2040_Mouse.kicad_pcb]
2023-01-21 Fix footprint issue from 2nd PCB run, pannelize for prod, new pics, new label
    [RP2040_Mouse.kicad_pcb, RP2040_Mouse.kicad_sch]
2023-01-21 Upgrade to KiCAD 6.99 (Nightly)
    [RP2040_Mouse.kicad_pcb, RP2040_Mouse.kicad_sch]
2023-01-21 Break up schematic into hierarchical sheets
    [MCU.kicad_sch, RP2040_Mouse.kicad_pcb, indication.kicad_sch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]
2023-02-03 Rev 5 update
    [MCU.kicad_sch, RP2040_Mouse.csv, RP2040_Mouse.kicad_pcb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]
2023-02-24 Rev 6
    Fully rerouted the board to make it cheaper and easier to make at PCBWay
    [MCU.kicad_sch, RP2040_Mouse.kicad_pcb, RP2040_Mouse.kicad_sch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]

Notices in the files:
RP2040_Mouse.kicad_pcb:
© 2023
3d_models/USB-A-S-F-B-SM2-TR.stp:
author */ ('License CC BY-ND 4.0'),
